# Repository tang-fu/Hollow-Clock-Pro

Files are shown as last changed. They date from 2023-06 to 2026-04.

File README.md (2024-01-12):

# Hollow-Clock-Pro

一款具有RGB，采用3D打印，指针悬浮的时钟

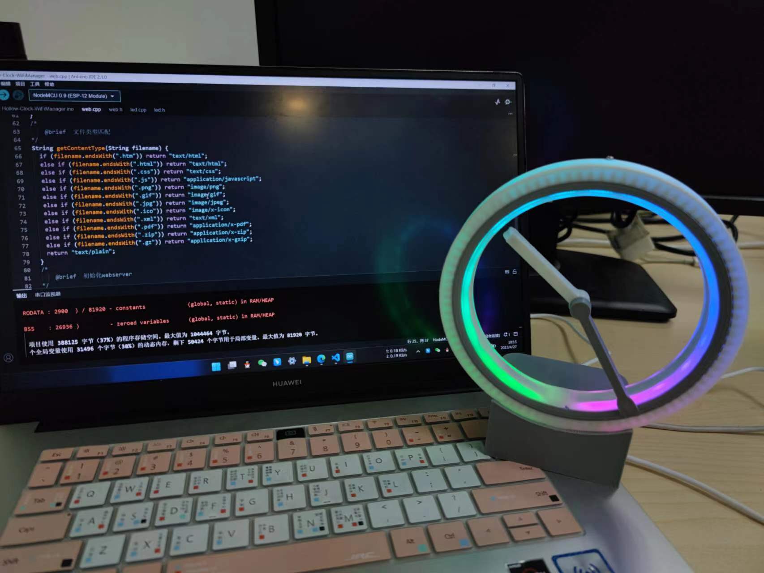
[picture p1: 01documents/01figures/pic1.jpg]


## 日志

- 2024/1/11：新增硬件描述，修改简介

## 声明 

该项目原作者为[shiura](https://www.youtube.com/@shiura/about)创作的作品[Hollow-Clock-4](https://www.instructables.com/Hollow-Clock-4/)  

**本项目基于原作的 CC-BY-NC-SA 4.0 协议 在原项目基础上做出改进，不用做商业用途，仅供学习参考使用**

## 简介

不得感叹原作本人的脑洞，原版的[Hollow-Clock-4](https://www.instructables.com/Hollow-Clock-4/)使用单片机自带时钟，存有一定时间误差，且其底座空间小，布局不合理。此项目在原有基础上做了一些改进。

### 功能说明

- wifi校时功能（第一次使用手动拨回12点）

- 新增WS18B20灯带，预置了3种灯效
- 新增了一键自动配网功能，链接时钟热点进行wifi配置
- 支持反转校时（结构问题，暂未使用）
- 新增网页界面控制时钟，可自行内置其他功能
- 新增OTA远程升级
- 重新绘制PCB
- 新外壳模型设计

### 注意事项

该项目没有采用电池供电方案，有需求的小伙伴请自行修改设计，因为电机功耗较大，常规3.7锂电池挺不了多久~

### 开发环境

| 主体 |  平台 |
| :---: | :-----: |
| lower——>Hollow-Clock-Pro | Aruidno |
| lower——>data——>html | Vscode  |

## 文件说明

### 01documents

存放项目所有文档，表格，图片

### 02industial_design

存放3D模型文件等，[点击跳转文档说明](./01documents/02industrial_design_doc)

### 03electronic_design

项目EDA工程文件，[点击跳转文档说明](./01documents/03electronic_design_doc)

### 04lower

下位机工程文件，[点击跳转文档说明](./01documents/04lower_doc)

### 05upper

上位机工程文件，[点击跳转文档说明](./01documents/05upper_doc)

## 使用说明

- [演示视频，校时教程](https://www.bilibili.com/video/BV1DL41167Pf/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)  
- 如果你已经准备好了整套设备，并且已经组装完成，请参考[使用说明书，点击跳转](https://docs.qq.com/pdf/DS01uWlNuZ0xRZk10)

## 项目展示

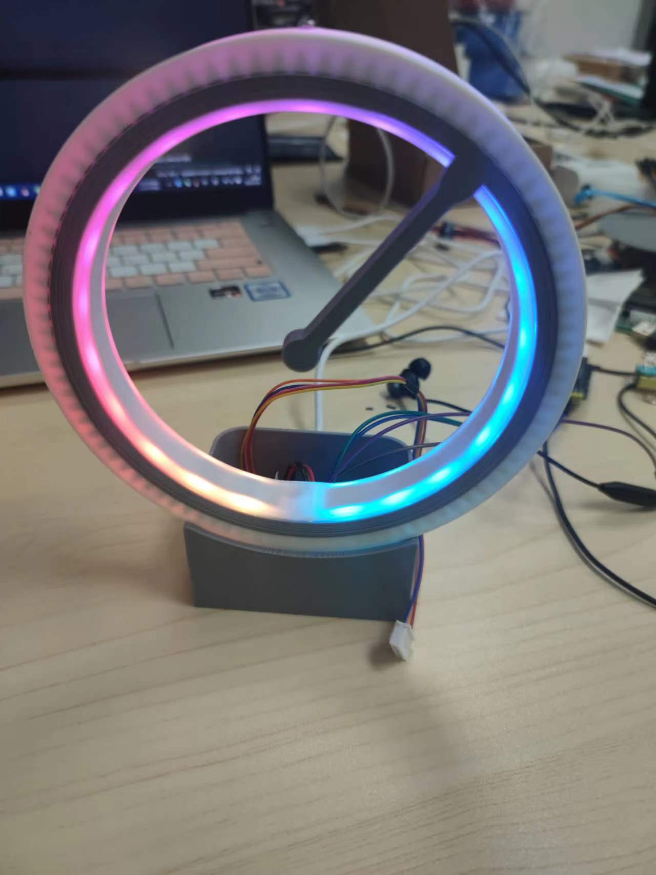
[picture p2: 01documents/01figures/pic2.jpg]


## 赞助

如果你觉得这个项目对你有帮助，或者你有新的想法，欢迎你在此基础上继续创作  

并且情况允许的话，可以给我点一下star吗，总之非常感谢支持～

## License

This project is licensed under a [Creative Commons Attribution-NonCommercial-ShareAlike 4.0 International License](https://creativecommons.org/licenses/by-nc-sa/4.0/).

## 鸣谢

感谢嘉立创大大提供的免费PCB!

感谢[@魔光堂_来一点光](https://gitee.com/link?target=https%3A%2F%2Fspace.bilibili.com%2F65500598)提供wifi自主校时的思路

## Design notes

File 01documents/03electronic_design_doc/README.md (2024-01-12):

# Eletronic_design相关说明

## 硬件BOM

相关硬件BOM表，将EDA工程文件，导入立创EDA，可一键生成BOM。

## 元器件采购

- 立创商城采购

- Eletronic_design文档中有淘宝店铺的Excel表

## 其他说明

### 灯带说明

本项目采用的是WS2812B灯带，接口如下图：  



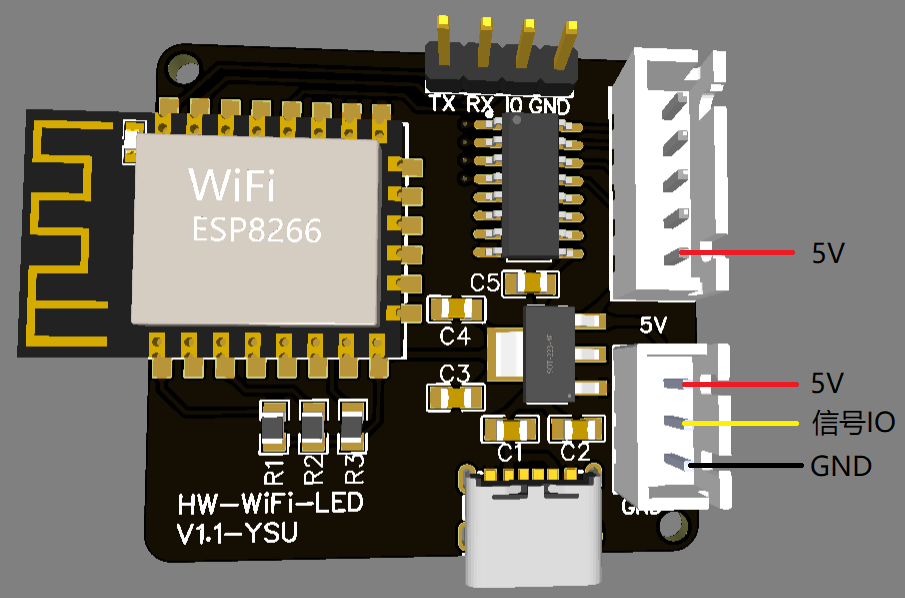
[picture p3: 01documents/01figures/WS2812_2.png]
- 由于网上买到的灯带接口不统一，本人建议自己改线，PCB的led接口采用XH2.54母头插座，3Pin。如下图

- 推荐自行购买XH2.54公头线，焊接在灯带上即可，且和电机的插头形成统一
- 当然也可以自行焊接2.54mm排针，然后用arduino的杜邦线插上即可，这种接线可能会松，但也能用
- 关于WS2812灯带，宽度<=1cm，推荐裸灯带，不建议使用滴胶灯带，厚度可能不符合，未经验证

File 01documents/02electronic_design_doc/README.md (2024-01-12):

# Eletronic_design相关说明

## 硬件BOM

相关硬件BOM表，将EDA工程文件，导入立创EDA，可一键生成BOM。

## 元器件采购

- 立创商城采购

- Eletronic_design文档中有淘宝店铺的Excel表

## 其他说明

### 灯带说明

本项目采用的是WS2812B灯带，接口如下图：  



- 由于网上买到的灯带接口不统一，本人建议自己改线，PCB的led接口采用XH2.54母头插座，3Pin。如下图
- 推荐自行购买XH2.54公头线，焊接在灯带上即可，且和电机的插头形成统一
- 当然也可以自行焊接2.54mm排针，然后用arduino的杜邦线插上即可，这种接线可能会松，但也能用
- 关于WS2812灯带，宽度<=1cm，推荐裸灯带，不建议使用滴胶灯带，厚度可能不符合，未经验证

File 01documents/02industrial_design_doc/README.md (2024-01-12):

# Industrial_design相关说明

## 3D模型介绍

其中包含两套模型

新模型示例如下,未经验证

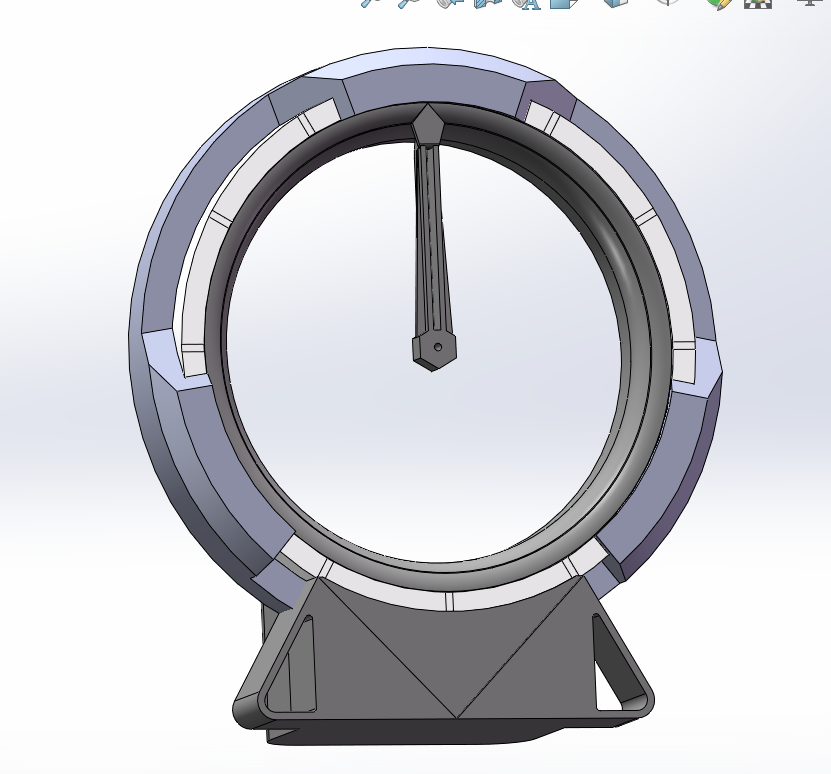
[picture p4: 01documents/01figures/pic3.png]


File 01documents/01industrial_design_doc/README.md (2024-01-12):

# Industrial_design相关说明

## 3D模型介绍

其中包含两套模型

新模型示例如下,未经验证



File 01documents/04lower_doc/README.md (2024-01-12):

# Lower相关说明 

## 环境准备

请使用ArduinoIDE2.0以下的版本

## 代码烧录

具体分为两次烧录
- 烧录hollow-clock-pro.ino到esp8266  
编译前请提前安装相关的依赖库文件  
- 烧录data目录到esp8266  
该目录存放网页相关文件 
具体用于烧录到8266的flash中，以便快速响应  
data目录具体烧录方法参考链接[点击传送](http://www.taichi-maker.com/homepage/esp8266-nodemcu-iot/iot-c/spiffs/upload-files/)

## 相关说明

### 灯带控制

#### 灯效

新增或修改灯效  

1. 请在led.cpp文件中led_control()函数中新增或修改函数选项  
2. 并在头文件led.h自定义宏  
3. 新增web.cpp中handleLED()函数选项 
4. 修改data中的网页文件

#### 灯珠数量

灯珠数量：更具自己喜好即可 根据灯珠数量，修改led.h中的宏参数`NUM_LEDS`，其中默认为21颗灯珠，不建议太多灯珠，板子功耗未经测试

### 驱动板控制

关于自行使用ESP8266nodemcu控制ULN2003驱动板和LED灯带，请修改`led.h`文件中的第5行的LED控制IO，修改`.ino`文件中第28行的`int` 所对应的电机驱动控制IO

## 更新说明

暂无更新

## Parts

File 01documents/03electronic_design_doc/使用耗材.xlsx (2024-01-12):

悬浮时钟耗材清单
序号 | 名称 | 规格 | 数量 | 其他 | 链接
1 | 铷磁铁 | 8x3mm | 3 | \ | https://detail.tmall.com/item.htm?_u=6208vdvscldc6b&id=688278589050&skuId=5079320391220
2 | 步进电机 | 28BYJ-48 | 1 | \ | https://detail.tmall.com/item.htm?id=692505915896&spm=a1z0d.6639537/tb.1997196601.4.3e6d7484rMPSqC
4 | 自攻螺丝 | M2*4mm | 7 | \ | https://detail.tmall.com/item.htm?id=17518032298&spm=a1z0d.6639537/tb.1997196601.60.3e6d7484IOxLTM
5 | 自攻螺丝 | M2*10mm | 1 | \ | https://detail.tmall.com/item.htm?id=17518032298&spm=a1z0d.6639537/tb.1997196601.60.3e6d7484IOxLTM
6 | ESP12F | \ | 1 | 电子元件 | https://detail.1688.com/offer/668219016106.html?spm=a360q.8274423.0.0.49c84c9aHbBStA
7 | PCB板 | \ | 1 | 电子元件
8 | ASM1117-3.3 | 3.3V | 1 | 电子元件 | https://item.taobao.com/item.htm?spm=a1z10.3-c-s.w4002-24706531953.43.4be16a4b673sZm&id=653993223688
9 | ULN2003 | SOP-16 | 1 | 电子元件 | https://item.taobao.com/item.htm?spm=a1z10.3-c-s.w4002-24706531953.23.93e86a4bsWDwxJ&id=653404673743
10 | type-c | 6Pin | 1 | 电子元件 | https://item.taobao.com/item.htm?spm=a1z10.3-c-s.w4002-24706531953.12.3f156a4bEdJDAj&id=573089663803
11 | 10uF | 0805 | 2 | 电子元件 | https://item.taobao.com/item.htm?spm=a1z10.3-c-s.w4002-24706531953.13.24396a4beGsDLL&id=522553943922
12 | 0.1uF | 0805 | 3 | 电子元件 | https://item.taobao.com/item.htm?spm=a1z10.3-c-s.w4002-24706531953.28.58546a4bZXR6oA&id=522576552845
13 | 10kΩ | 0805 | 3 | 电子元件 | https://item.taobao.com/item.htm?spm=a1z10.3-c-s.w4002-24706531953.33.2de06a4be4IcaK&id=522573121620
14 | 外壳 |  | 1 | \

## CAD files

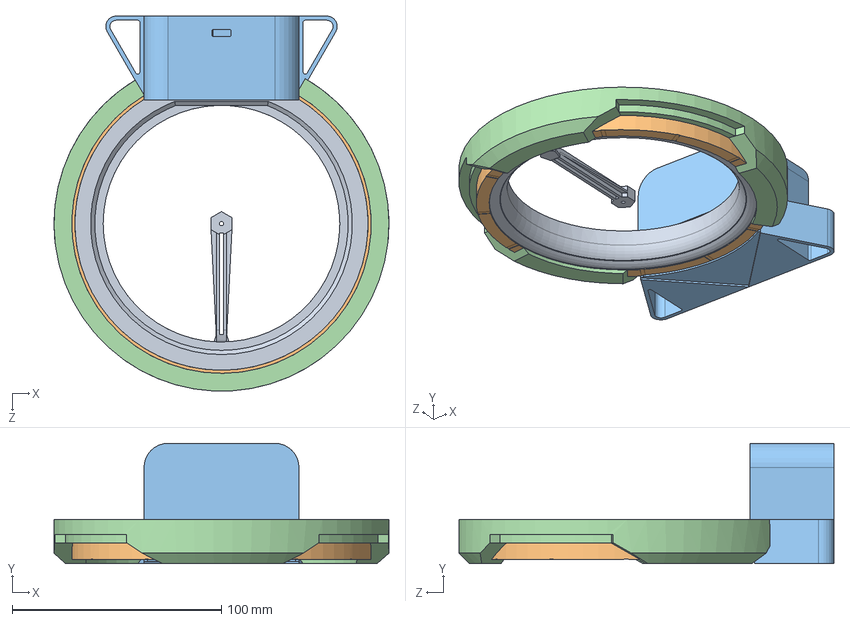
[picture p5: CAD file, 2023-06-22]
02industial_design/3Dmodel/style2/悬浮时钟.SLDASM
160.0 x 57.5 x 179.1 mm
钟体
悬浮钟外罩
底座
外壳装饰环

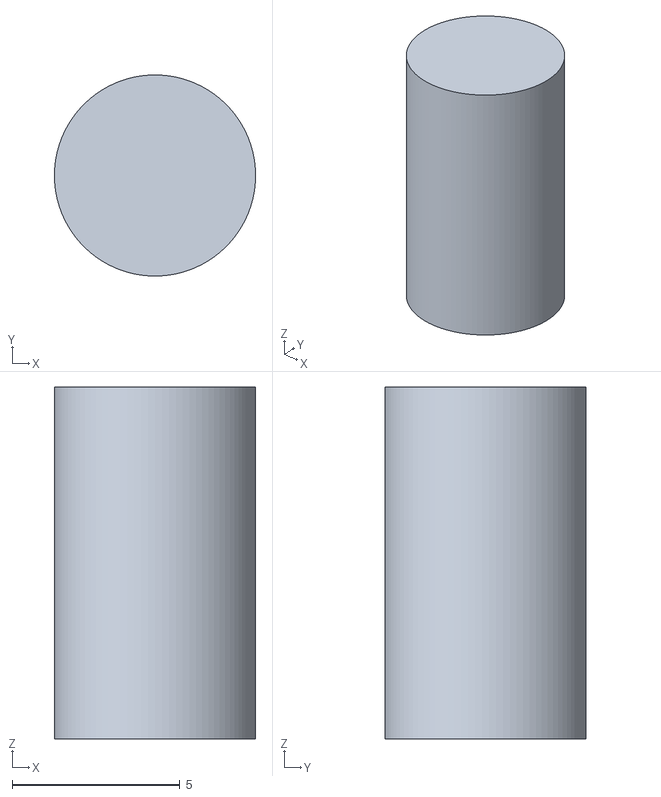
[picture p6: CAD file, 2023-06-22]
02industial_design/3Dmodel/style1/011圆柱轴.stl
6.00 x 6.00 x 10.5

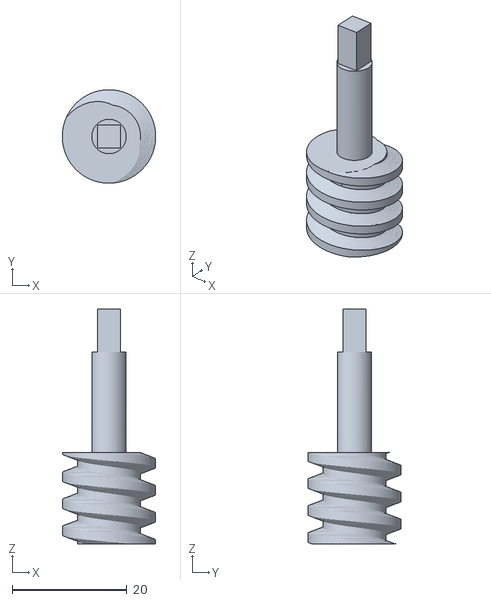
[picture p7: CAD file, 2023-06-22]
02industial_design/3Dmodel/style1/008旋转轴.stl
16.3 x 16.3 x 41.0

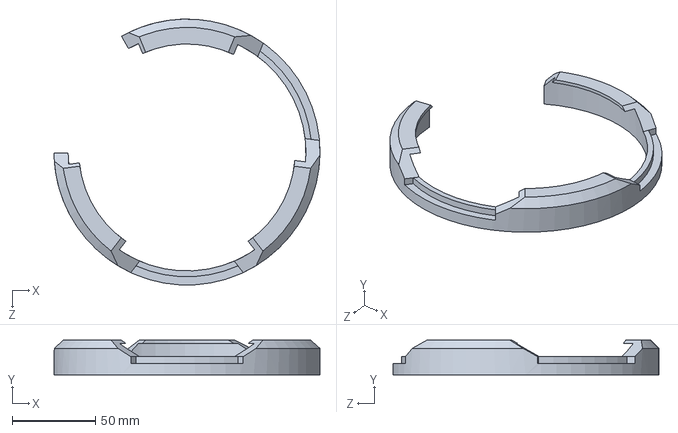
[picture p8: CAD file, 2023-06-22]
02industial_design/3Dmodel/style2/外壳装饰环.SLDPRT
160.0 x 21.0 x 159.8 mm

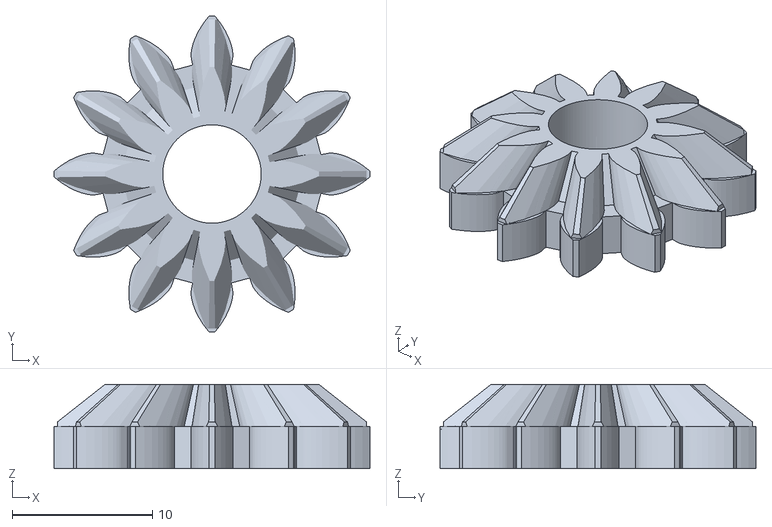
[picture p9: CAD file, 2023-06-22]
02industial_design/3Dmodel/style1/009-1大齿轮.stl
22.5 x 22.5 x 6.00

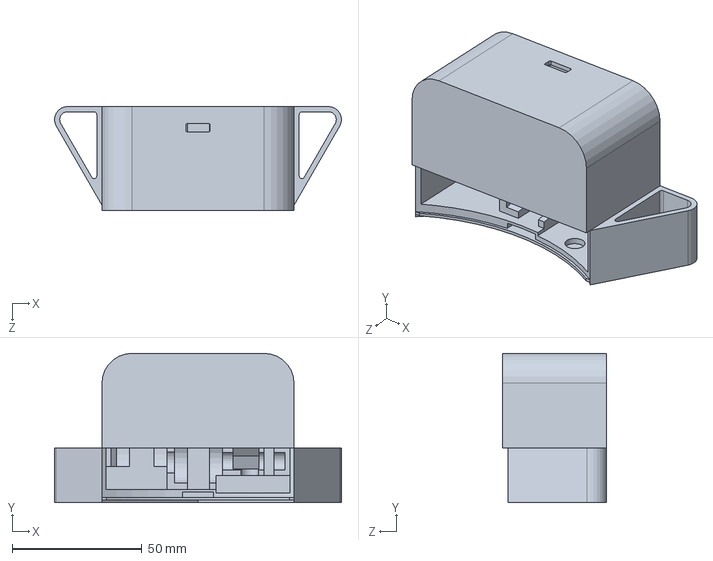
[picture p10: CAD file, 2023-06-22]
02industial_design/3Dmodel/style2/底座.SLDPRT
110.6 x 57.5 x 40.0 mm

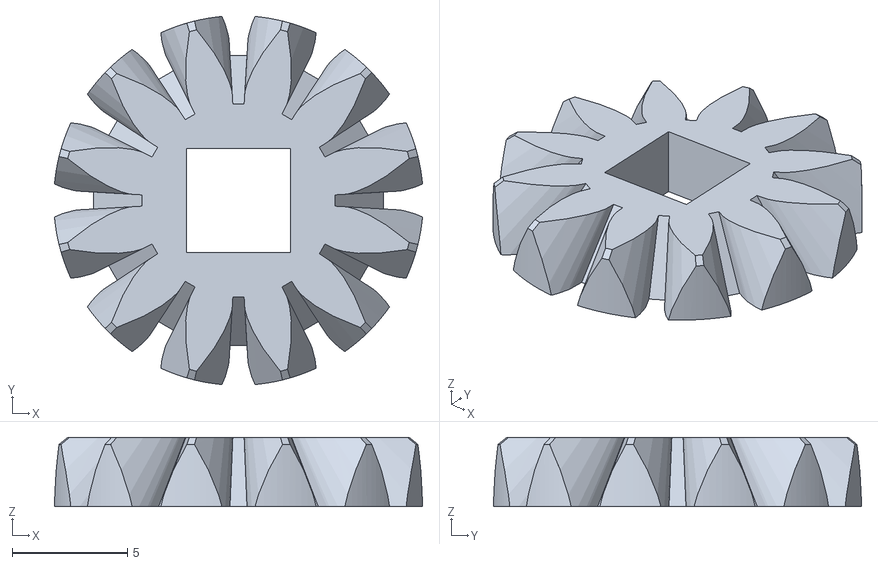
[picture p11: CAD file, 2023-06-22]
02industial_design/3Dmodel/style1/009-2小齿轮.stl
15.9 x 15.9 x 3.00

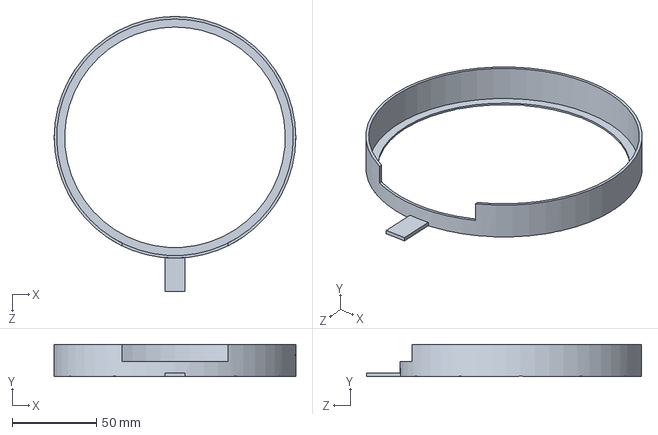
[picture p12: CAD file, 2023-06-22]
02industial_design/3Dmodel/style2/悬浮钟外罩.SLDPRT
143.0 x 19.0 x 162.7 mm

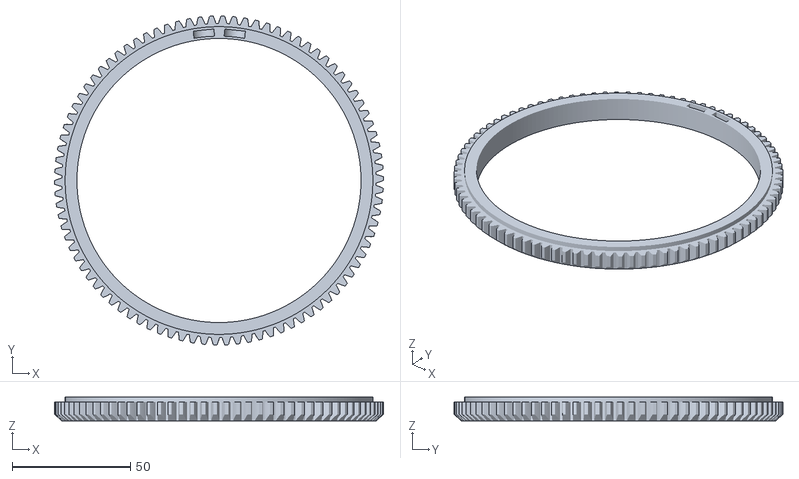
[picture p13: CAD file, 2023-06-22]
02industial_design/3Dmodel/style1/004时针转轴.stl
139.0 x 139.0 x 10.0

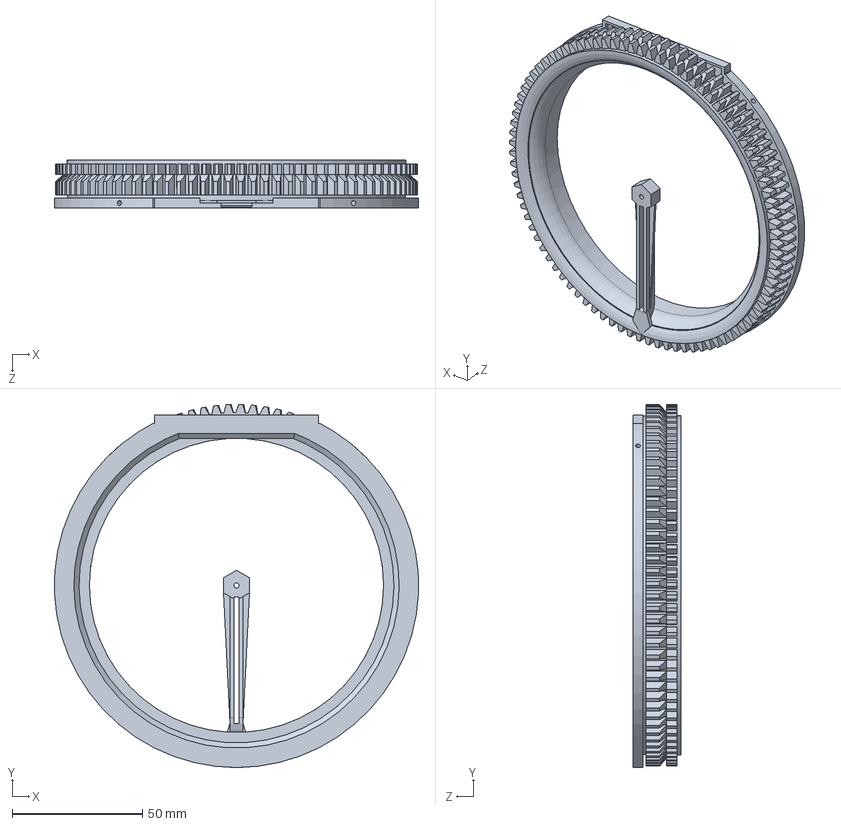
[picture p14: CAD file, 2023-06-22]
02industial_design/3Dmodel/style2/钟体.SLDPRT
139.9 x 139.5 x 18.6 mm

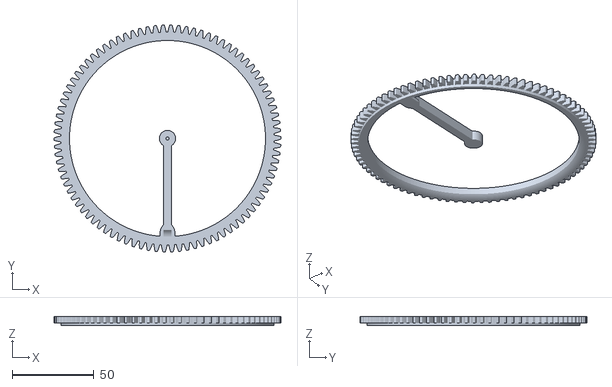
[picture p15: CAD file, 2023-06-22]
02industial_design/3Dmodel/style1/003分钟转轴.stl
139.0 x 139.0 x 5.50

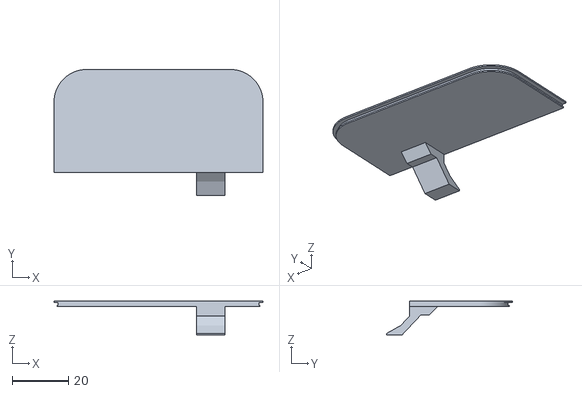
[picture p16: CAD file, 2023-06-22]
02industial_design/3Dmodel/style1/002底座盖.stl
74.0 x 44.6 x 12.0

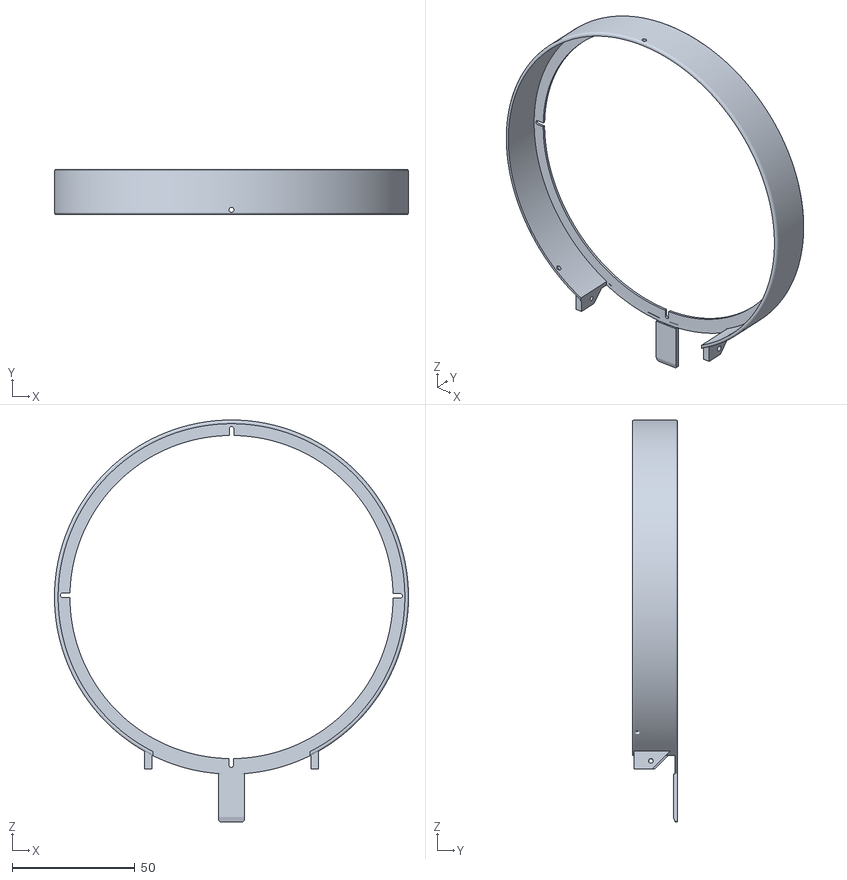
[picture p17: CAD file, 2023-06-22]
02industial_design/3Dmodel/style1/007前盖.stl
144.0 x 18.5 x 163.5

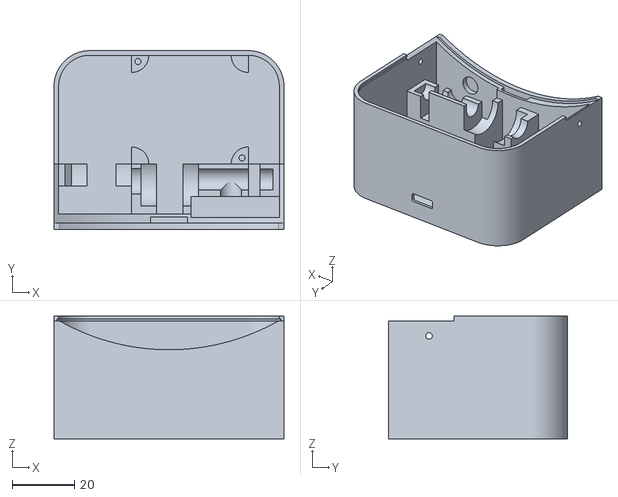
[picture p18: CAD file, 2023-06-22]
02industial_design/3Dmodel/style1/001底座.stl
74.0 x 57.5 x 39.5

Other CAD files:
02industial_design/3Dmodel/style1/006LED灯罩.stl
02industial_design/3Dmodel/style1/010时针指针.stl
02industial_design/3Dmodel/style1/005后盖.stl

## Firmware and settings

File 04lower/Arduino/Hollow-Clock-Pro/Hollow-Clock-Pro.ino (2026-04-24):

#include "web.h"
#include "led.h"
#include <ArduinoOTA.h>
#include <ESP8266WiFi.h>
#include <WiFiManager.h>
#include <NTPClient.h>
#include <WiFiUdp.h>
#include <ESP8266mDNS.h>

extern int LED_State;
extern int NIGHT_KEY;

#define STEPS_PER_ROTATION 30743  // 4096 * 90 / 12 = 30720 default

WiFiManager wifiManager;
String LocalIP = "";
WiFiUDP ntpUDP;
NTPClient timeClient(ntpUDP, "ntp2.aliyun.com", 60 * 60 * 8, 30 * 60 * 1000);  //偏移
int currentHour = 0;
int currentMinute = 0;
//int currentSeconds = 0;
int night_mode_flag1 = 23;  //默认夜间模式设置为23点——6点
int night_mode_flag2 = 6;

int dt = 20;
int delaytime = 1;
static long prev_pos, pos;
static int num, prev_min, cur_min;
int port[4] = { 16, 14, 12, 13 };
//int port[4] = { 13, 12, 14, 16 };
//int port[4] = { 15, 13, 12, 14 };//nodemcu
int seq[8][4] = {  // sequence of stepper motor control
  { LOW, HIGH, HIGH, LOW },
  { LOW, LOW, HIGH, LOW },
  { LOW, LOW, HIGH, HIGH },
  { LOW, LOW, LOW, HIGH },
  { HIGH, LOW, LOW, HIGH },
  { HIGH, LOW, LOW, LOW },
  { HIGH, HIGH, LOW, LOW },
  { LOW, HIGH, LOW, LOW }
};

void setup() {
  Serial.begin(115200);

  Led_Init();

  pinMode(port[0], OUTPUT);
  pinMode(port[1], OUTPUT);
  pinMode(port[2], OUTPUT);
  pinMode(port[3], OUTPUT);

  //wifiManager.setSTAStaticIPConfig(IPAddress(192, 168, 119, 45), IPAddress(192, 168, 119, 1), IPAddress(255, 255, 255, 0));  //配置静态ip
  wifiManager.autoConnect("Hollow-Clock-Pro");
  LocalIP = WiFi.localIP().toString().c_str();
  //wifiManager.resetSettings();//重置热点信息
  //Serial.println(WiFi.getMode());//查看WiFi模式

  timeClient.begin();
  for (num = 0; num < 10; num++) {
    timeClient.update();
    currentHour = timeClient.getHours();
    currentMinute = timeClient.getMinutes();
    Serial.print("当前时间:");
    Serial.print(currentHour);
    Serial.print(":");
    Serial.println(currentMinute);
  }
  Time_Correction(currentHour);

  ArduinoOTA.setHostname("Hollow_Clock_Pro");
  ArduinoOTA.setPassword("88888888");
  ArduinoOTA.begin();
  Server_Init();
  if (MDNS.begin("hollowclock")) {
    Serial.println("mDNS responder started");
    MDNS.addService("http", "tcp", 80);
  }
}

void loop() {
  ArduinoOTA.handle();
  Server_handle();

  Led_Control(LED_State);

  cur_min = Get_Current_Time();

  if (prev_min == cur_min) {
    return;
  }
  /*********************************************************/
  prev_min = cur_min;
  pos = (STEPS_PER_ROTATION * cur_min) / 60;
  if (pos > prev_pos) {
    rotate(pos - prev_pos);
  }
  //分钟数从60到1会使pos<prev_pos，需要特殊处理
  if (pos < prev_pos) {
    rotate(STEPS_PER_ROTATION / 60);
  }
  prev_pos = pos;
}
/**
    @brief  控制电机转动
    @param  none
    @retval none
*/
void rotate(int step) {
  static int i, j, phase = 0;
  int delta = (step > 0) ? 1 : 7;

  step = (step > 0) ? step : -step;
  for (j = 0; j < step; j++) {
    phase = (phase + delta) % 8;
    for (i = 0; i < 4; i++) {
      digitalWrite(port[i], seq[phase][i]);
    }
    delay(dt);
    if (dt > delaytime) dt--;
  }
  // power cut
  for (i = 0; i < 4; i++) {
    digitalWrite(port[i], LOW);
  }
}
/**
    @brief  获取当前网络时间
    @param  none
    @retval 返回分钟整数
*/
int Get_Current_Time() {
  timeClient.update();
  currentHour = timeClient.getHours();
  currentMinute = timeClient.getMinutes();
  //currentSeconds = timeClient.getSeconds();
  //Serial.println(currentMinute);//串口检查时间
  if (currentMinute == 0) {
    return 60;
  } else {
    return currentMinute;
  }
}
/**
    @brief  自动校时函数，根据当前网络时间，控制指针自动旋转到指定位置
*/
void Time_Correction(int hour) {
  Led_Control(LED_OFF);  //清除灯效
  int i = 0;
  if (hour >= 12) {
    hour -= 12;
  }
  Serial.print("当前正转校时 小时差为:");
  Serial.println(hour);
  for (i = 1; i <= NUM_LEDS; i++) {
    rotate(STEPS_PER_ROTATION * hour / NUM_LEDS);
    Led_Control(LED_TIME_CORRECTION);
  }
  Serial.println("校准完毕");


  Led_Control(LED_OFF);
}

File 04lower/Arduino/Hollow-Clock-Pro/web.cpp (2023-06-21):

#include <ESP8266WebServer.h>
#include <FS.h>
#include "led.h"

extern int LED_State;
extern int currentHour;
extern int currentMinute;
extern String LocalIP;
extern int NIGHT_KEY;
extern int night_mode_flag1;
extern int night_mode_flag2;

String getContentType(String filename);
void handleLED();
void handleTime();
void handleUserRequest();
bool handleFileRead(String resource);
void Server_Init();
void Server_handle();
void handle_Night_Mode();
void handle_Night_Mode_State();

ESP8266WebServer server(80);

void handleLED() {
  String LED = server.arg("LEDstate");
  // Serial.print("接受到指令:");
  // Serial.println(LED);
  if (LED == "1") {
    LED_State = LED_ON;  //工作灯效
    //Serial.println("打开工作灯效");
  }
  if (LED == "0") {
    LED_State = LED_OFF;  //关闭灯效
  }
  if (LED == "3") {
    LED_State = LED_BLUE;  //银蓝流水灯效
  }
  if (LED == "4") {
    LED_State = LED_GRADIENT;  //渐变流水灯效
  }
}
/*
    @brief  处理网络时间
*/
void handleTime() {
  String TimeValue = String(currentHour) + ":" + String(currentMinute);
  server.send(200, "text/plain", TimeValue);
}
/*
    @brief  返回LocalIP
*/
void handleIP() {
  server.send(200, "text/plain", LocalIP);
}
/*
    @brief  夜间模式开关
*/
void handle_Night_Mode() {
  String night = server.arg("Night_Mode_Value");
  if (night == "1") {
    NIGHT_KEY = 1;  //夜间模式开
  }
  if (night == "0") {
    NIGHT_KEY = 0;
  }
}
//夜间模式状态
void handle_Night_Mode_State() {
  String NightMode = "";
  if (NIGHT_KEY == 1) {
    NightMode = "ON";
  }
  if (NIGHT_KEY == 0) {
    NightMode = "OFF";
  }
  server.send(200, "text/plain", NightMode);
}
void Set_Night_Time() {
  String time1 = server.arg("time1");
  String time2 = server.arg("time2");
  int value1 = time1.toInt();
  int value2 = time2.toInt();
  night_mode_flag1 = value1;
  night_mode_flag2 = value2;
}
/*
    @brief  其他处理函数
*/
void handleUserRequest() {
  String reqResource = server.uri();              //获取用户请求资源
  bool fileReadOK = handleFileRead(reqResource);  //通过handleFileRead函数处处理用户请求资源
  if (!fileReadOK) {
    server.send(404, "text/plain", "404 Not Found");
  }
}
/*
    @brief  处理用户访问文件，并判断是否存在,处理浏览器HTTP访问
*/
bool handleFileRead(String resource) {
  if (resource.endsWith("/")) {  // 如果访问地址以"/"为结尾
    resource = "/index.html";    // 则将访问地址修改为/index.html便于SPIFFS访问
  }

  String contentType = getContentType(resource);  // 获取文件类型

  if (SPIFFS.exists(resource)) {             // 如果访问的文件可以在SPIFFS中找到
    File file = SPIFFS.open(resource, "r");  // 则尝试打开该文件
    server.streamFile(file, contentType);    // 并且将该文件返回给浏览器
    file.close();                            // 并且关闭文件
    return true;                             // 返回true
  }
  return false;  // 如果文件未找到，则返回false
}
/*
    @brief  文件类型匹配
*/
String getContentType(String filename) {
  if (filename.endsWith(".htm")) return "text/html";
  else if (filename.endsWith(".html")) return "text/html";
  else if (filename.endsWith(".css")) return "text/css";
  else if (filename.endsWith(".js")) return "application/javascript";
  else if (filename.endsWith(".png")) return "image/png";
  else if (filename.endsWith(".gif")) return "image/gif";
  else if (filename.endsWith(".jpg")) return "image/jpeg";
  else if (filename.endsWith(".ico")) return "image/x-icon";
  else if (filename.endsWith(".xml")) return "text/xml";
  else if (filename.endsWith(".pdf")) return "application/x-pdf";
  else if (filename.endsWith(".zip")) return "application/x-zip";
  else if (filename.endsWith(".gz")) return "application/x-gzip";
  return "text/plain";
}
/*
    @brief  初始化webserver
*/
void Server_Init() {
  if (SPIFFS.begin()) {  // 启动闪存文件系统
    Serial.println("SPIFFS Started");
  } else {
    Serial.println("SPIFFS Failed to Start");
  }

  server.on("/getIP", handleIP);
  server.on("/setLED", handleLED);
  server.on("/readTime", handleTime);
  server.on("/Night_Mode", handle_Night_Mode);
  server.on("/Set_Night_Time", Set_Night_Time);
  server.on("/Night_Mode_State", handle_Night_Mode_State);
  server.onNotFound(handleUserRequest);
  server.begin();
}
/*
    @brief  监听客户请求并处理
*/
void Server_handle() {
  server.handleClient();
}

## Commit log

2023-06-21 删除文件 .gitignore
2023-06-21 删除文件 README.en.md
2023-06-21 删除文件 README.md
2023-06-21 add pcb sch profile
2023-06-21 新建 Docs
2023-06-21 新建 Pic
2023-06-22 commit 3dmodels
    [001底座.stl, 002底座盖.stl, 003分钟转轴.stl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]
2024-01-12 [Update]Update whole project
    [001底座.stl, 002底座盖.stl, 003分钟转轴.stl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]
2024-01-12 [Doc]update doc
    [使用耗材.xlsx]
